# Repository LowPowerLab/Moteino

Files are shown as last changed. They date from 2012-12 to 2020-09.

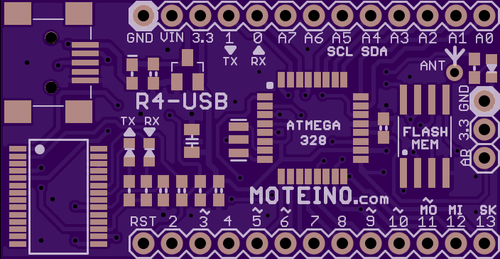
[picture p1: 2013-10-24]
R4USB/Rendering_top.png

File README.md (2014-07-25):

Moteino
=======

Moteino Eagle project and library.
Moteino is now shipping with DualOptiboot: https://github.com/LowPowerLab/DualOptiboot
DualOptiboot allows for wireless programming using an external FLASH chip soldered to Moteino on the provided footprint.

#License
CC-BY-SA 4.0
https://creativecommons.org/licenses/by-sa/4.0/
You are free to share and adapt. But you need to give attribution and use the same license to redistribute.

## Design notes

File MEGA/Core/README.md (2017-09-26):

# Moteino/MoteinoMEGA Arduino core files for Atmega328P/ATmega1284P based Moteinos

# * ~~~ Obsolete ~~~ *
See new instructions to get Moteino Core in the [Moteino guide](https://lowpowerlab.com/guide/moteino/programming-libraries/).

## What is it?
Everything you need to run a ATmega1284P based Moteino MEGA from the Arduino IDE.
Added regular Moteino variant based on the prolific ATmega328p.

## Status
* This Arduino core contains the ATmega1284P MoteinoMEGA variant and the ATmega328p Moteino variant (added Nov 2014) along with the DualOptiboot bootloaders.
* The platform now includes Dualoptiboot for ATmega1284P and ATmega328p which support [wireless programming](https://lowpowerlab.com/guide/moteino/wireless-programming/) (C) by Felix Rusu of LowPowerLab.com
* Last updated: Aug 24, 2016.

## License
This program is free software; you can redistribute it and/or modify it under the terms of the GNU General Public License as published by the Free Software Foundation; either version 3 of the License, or (at your option) any later version. This program is distributed in the hope that it will be useful, but WITHOUT ANY WARRANTY; without even the implied warranty of MERCHANTABILITY or FITNESS FOR A PARTICULAR PURPOSE. See the GNU General Public License for more details. View full license text at: http://www.gnu.org/licenses/gpl-3.0.txt

##Install Update
* This guide and package is only relevant for manual installs on IDE 1.6+ or the older 1.0.6.
* Arduino IDE 1.6.4+ has a board manager that makes it really easy to add the board definitions, instead of using these ZIP files. For installing via BoardManager in IDE 1.6.4+, see [this guide](https://lowpowerlab.com/moteino/#programming).

## Installation
0. Ensure you are running Arduino 1.6.0 or greater (this was tested on Arduino 1.6.9). For Arduino 1.0.6 use the Moteino_1.0.6.zip instead, read below.
1. Download the root of this repository [from here](https://github.com/LowPowerLab/Moteino) (find the "Clone or Download" button), then extract the Moteino core [ZIP File](https://github.com/LowPowerLab/Moteino/blob/master/MEGA/Core/Moteino.zip) from that. If you run the 1.0.6 release get the Moteino_1.0.6.zip instead.
2. From the master ZIP archive of the whole repository, find the [corresponding Moteino.zip file](https://github.com/LowPowerLab/Moteino/blob/master/MEGA/Core/Moteino.zip)
3. Unzip the content of the Moteino.zip into a folder called 'hardware' located in your sketches directory, e.g. /Users/felix/Arduino/hardware/Moteino. Some users report that they can only make this work by copying it directly in the hardware folder under their Arduino installation folder.
4. Restart the IDE
5. Select Tools > Board > Moteino or MoteinoMEGA
6. To burn the bootloader, follow the Arduino [Bootloader](http://arduino.cc/en/Hacking/Bootloader) instructions.

## Requirements
* Tested on stable Arduino 1.6.9
* According to maniacbug the bootloader cannot be burned using [USBtinyISP](http://www.ladyada.net/make/usbtinyisp/). That programmer cannot flash to chips with >64k flash size. I recommend using a true AVR programmer like the AVR ISP MKii.

## MISC - See also
ManiacBug's older [mighty-1284p arduino core](http://maniacbug.wordpress.com/2011/11/27/arduino-on-atmega1284p-4/) and 
Leonardo Milliani's [mods to mighty-1284p](http://www.leonardomiliani.com/2014/core-per-atmega644p1284p-aggiornato-per-lide-1-5-6-r2/).

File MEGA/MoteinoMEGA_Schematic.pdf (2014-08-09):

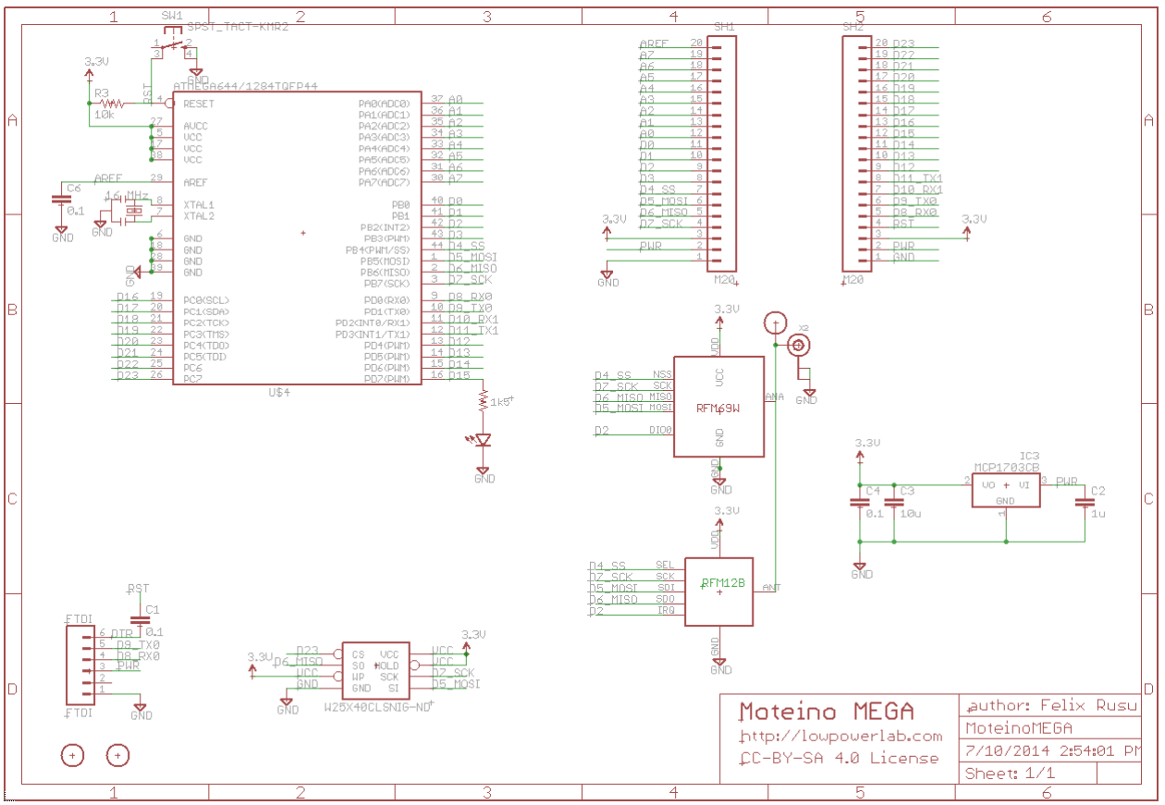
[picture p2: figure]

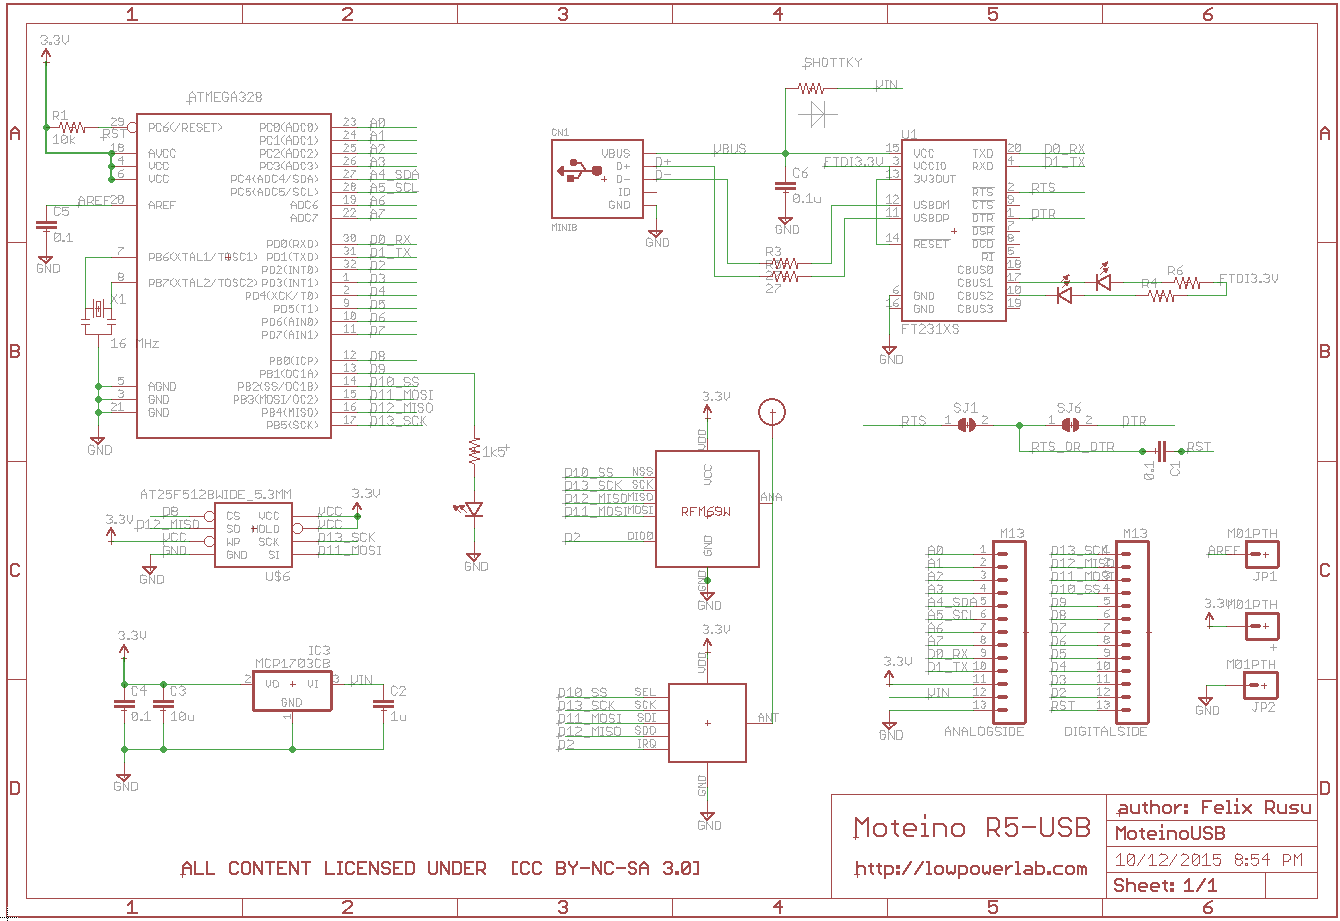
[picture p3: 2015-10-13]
R5USB/MoteinoR5USB_Schematic.png

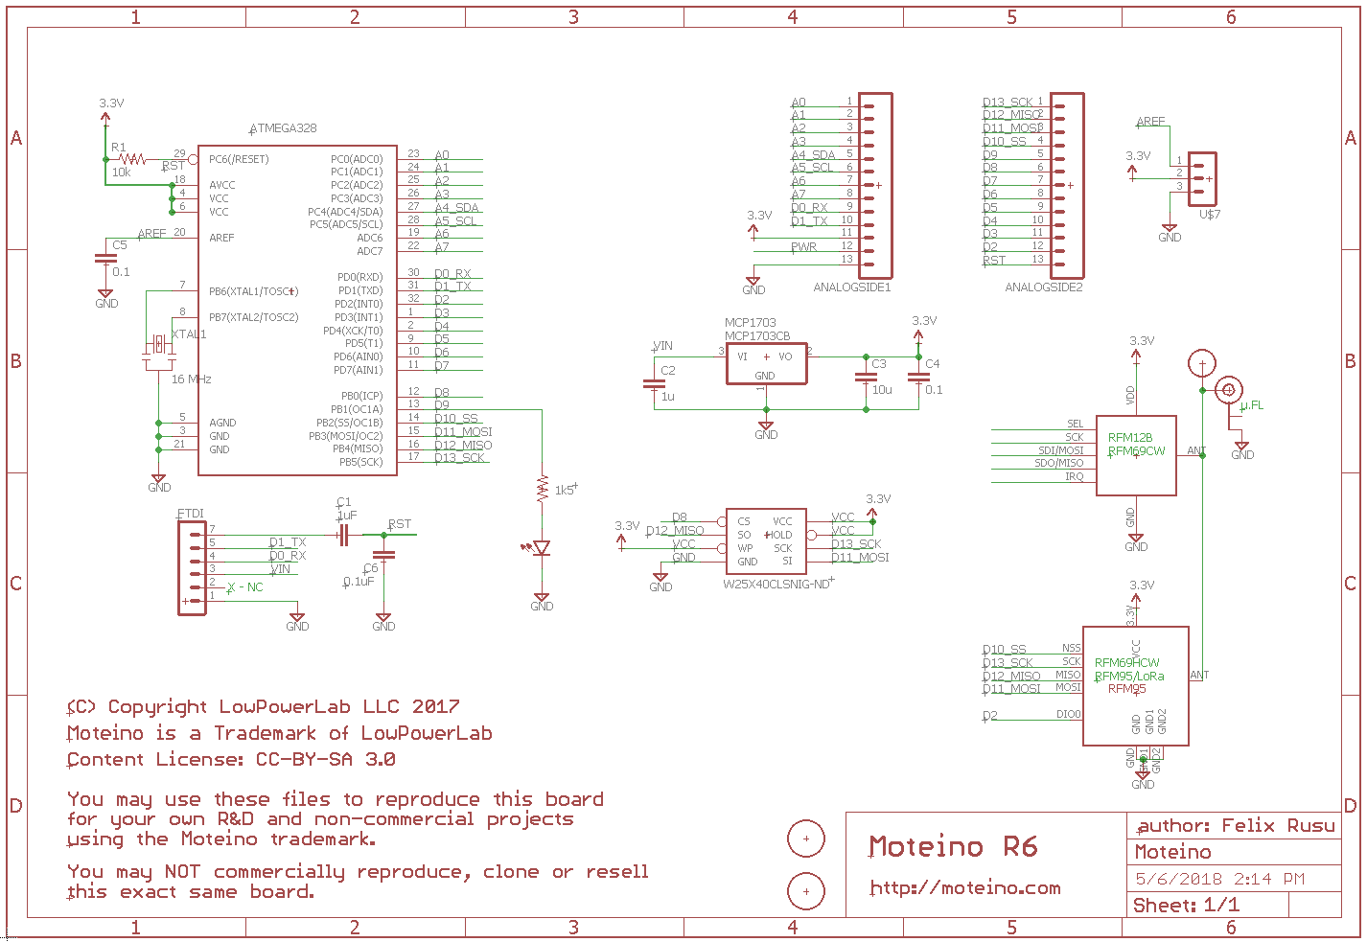
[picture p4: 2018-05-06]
R6/MoteinoR6_Schematic.png

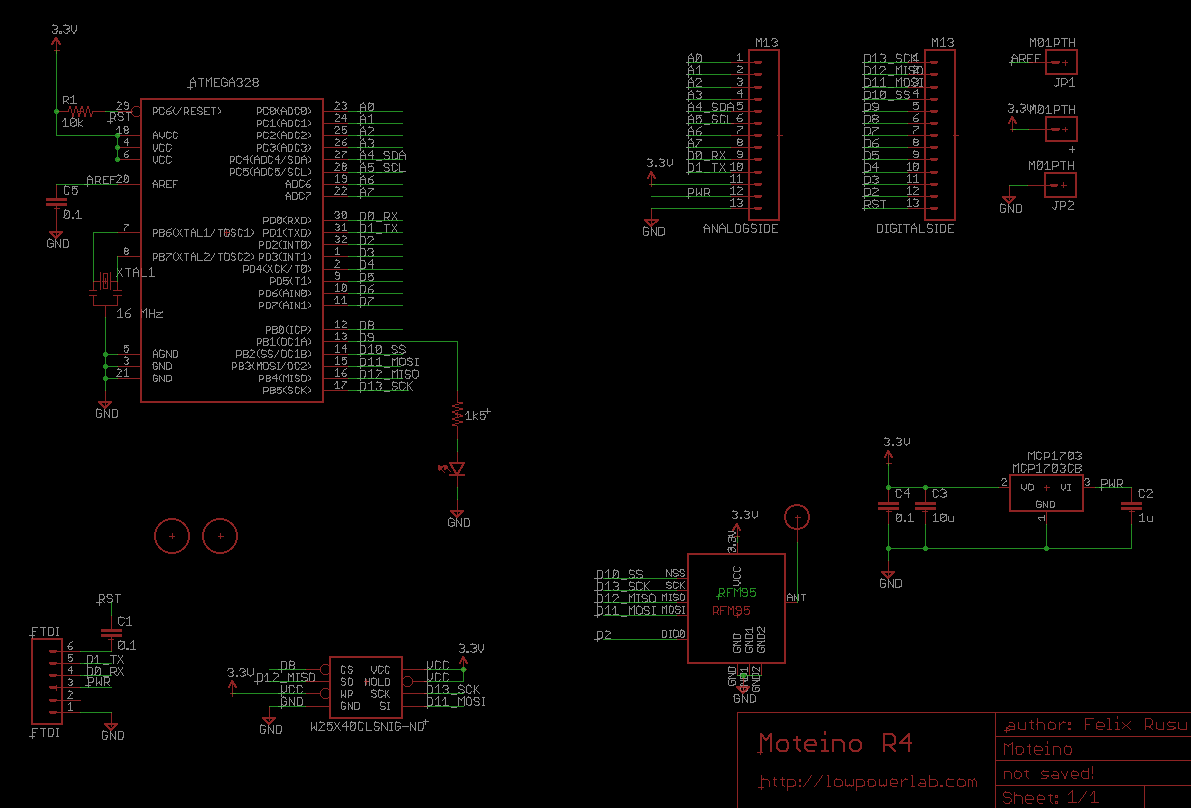
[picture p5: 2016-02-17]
R4/MoteinoR4LR_Schematic.png

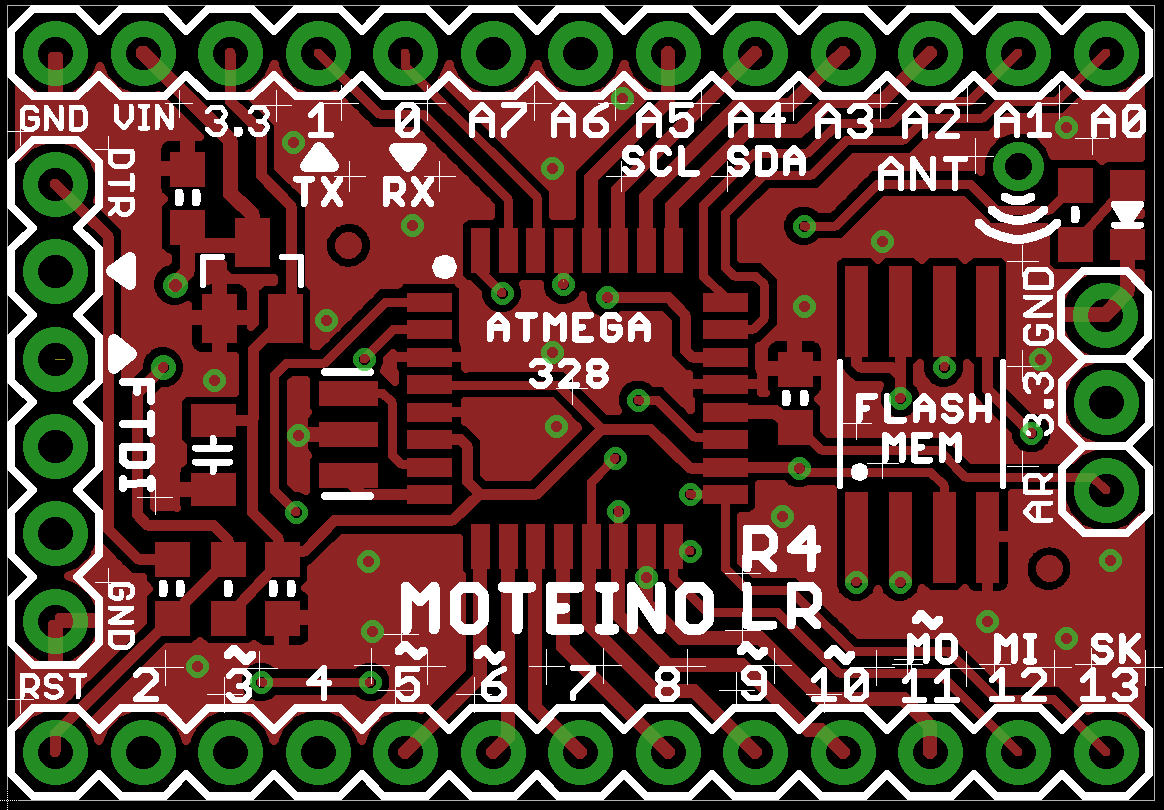
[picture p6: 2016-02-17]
R4/MoteinoR4LR_BRD_TOP.png

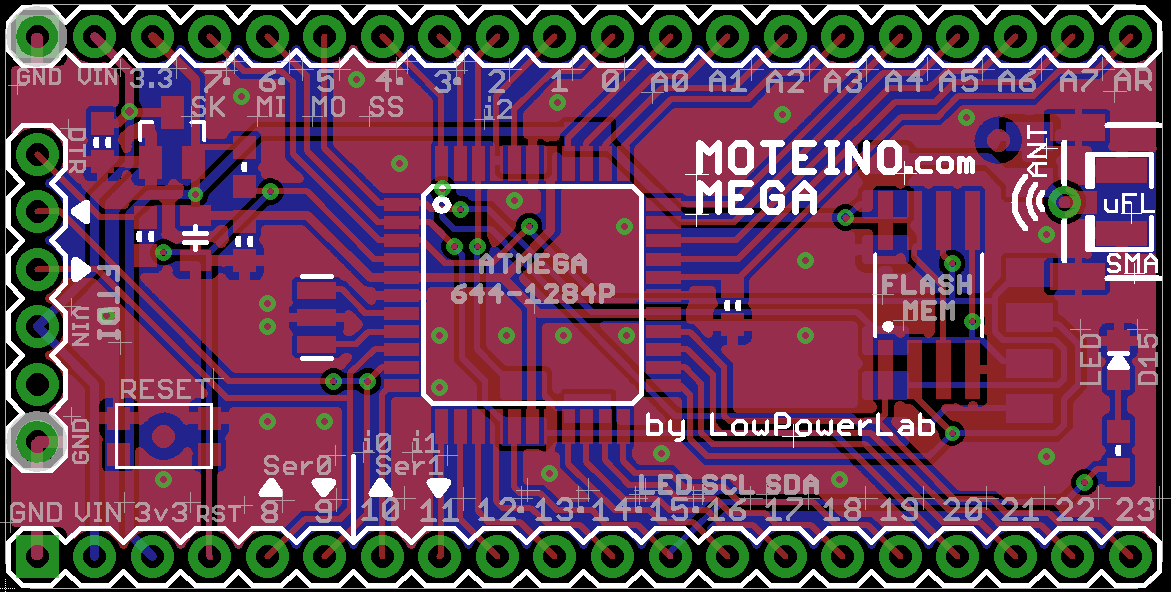
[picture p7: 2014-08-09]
MEGA/MoteinoMEGA_Board.png

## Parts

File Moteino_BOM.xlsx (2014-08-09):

 | QTY
MOTEINO
ATMega328P-AU TQFP32 | 1 | http://www.digikey.com/product-detail/en/ATMEGA328P-AU/ATMEGA328P-AU-ND/1832260
ATMega1284P-AU TQFP44 | 1 | http://www.digikey.com/product-detail/en/ATMEGA1284P-AU/ATMEGA1284P-AU-ND/1914519
Ceramic Res SMD 16Mhz | 1 | http://www.digikey.com/product-detail/en/CSTCE16M0V53-R0/490-1198-1-ND/584635
cap 0.1uf 0603 | 4 | http://www.digikey.com/product-detail/en/CC0603KRX7R7BB104/311-1088-1-ND/302998?cur=USD
cap 10uF | 1 | http://www.digikey.com/product-detail/en/CC0805ZKY5V6BB106/311-1355-1-ND/2103139
res 10k 0603 | 1 | http://www.digikey.com/product-detail/en/RC0603JR-0710KL/311-10KGRCT-ND/729647?cur=USD
MCP1703 3v3 (up to 16V in) | 1 | http://www.digikey.com/product-detail/en/MCP1703T-3302E%2FCB/MCP1703T-3302E%2FCBCT-ND/1776945
RFM12B | 1 | www.lowpowerlab.com/shop
RFM69 |  | www.lowpowerlab.com/shop
LED yellow - 0603 | 1 | http://www.digikey.com/product-detail/en/LY%20L29K-H1K2-26-Z/475-1196-1-ND/810357
res 1.5k 0603 (for LED) | 1 | http://www.digikey.com/scripts/DKSearch/dksus.dll?Detail&itemSeq=123239606&uq=634903057332793783
male headers | ? | http://www.digikey.com/product-detail/en/PRPC040SAAN-RC/S1011EC-40-ND/2775214
female headers | ? | http://www.digikey.com/product-detail/en/NPPN401BFCN-RC/S5751-40-ND/804821
PCB | 1 | Your favorite PCB fab
WIRE for antenna | 1 | 433Mhz:164.7mm, 868Mhz:82.2mm, 915Mhz:77.9mm (from here: http://blog.strobotics.com.au/2008/06/17/rfm12-tutorial-part2/)
You can use 1uF instead of 0.1uF
cap 1uf 0603 |  | http://www.digikey.com/product-detail/en/C1608Y5V1A105Z/445-1328-1-ND/567635

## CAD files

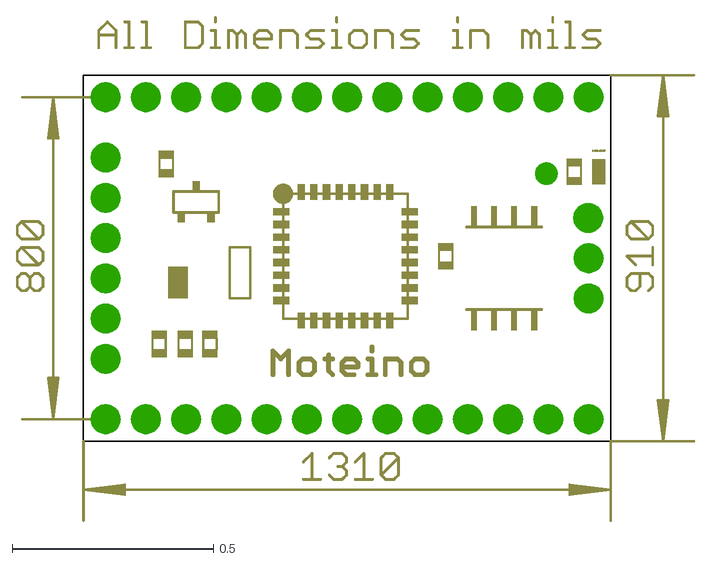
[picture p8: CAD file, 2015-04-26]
DXF/Moteino.dxf
1.69 x 1.26

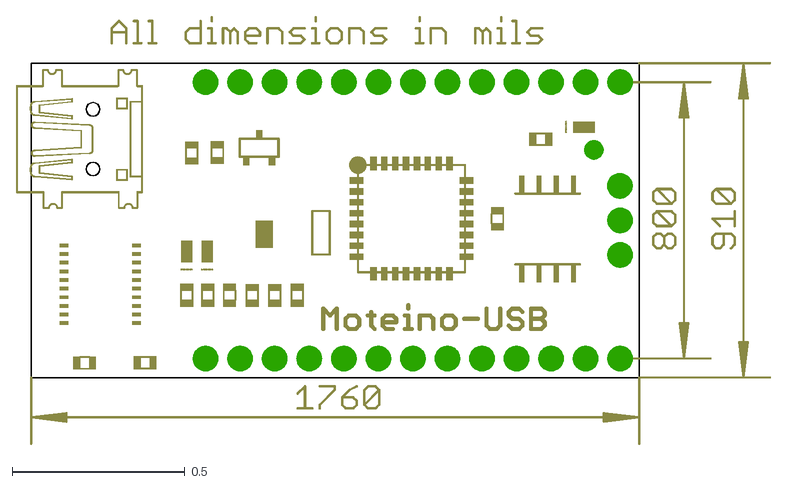
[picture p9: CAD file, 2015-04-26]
R5USB/MoteinoR5USB_dimension.dxf
2.18 x 1.24

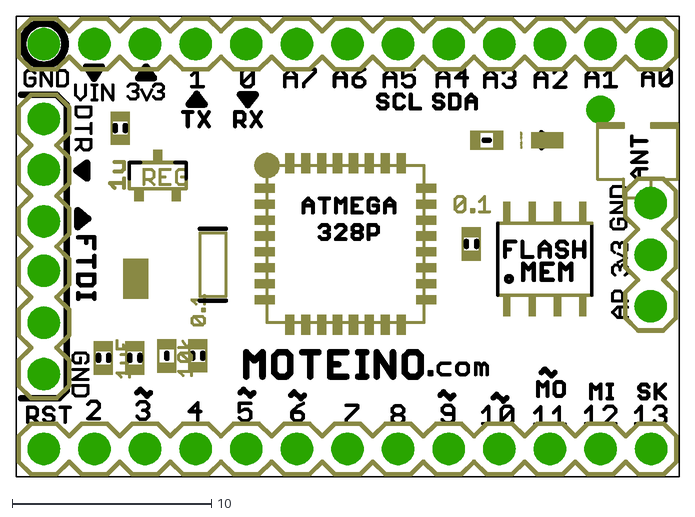
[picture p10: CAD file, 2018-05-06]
R6/Moteino.dxf
33.3 x 23.1

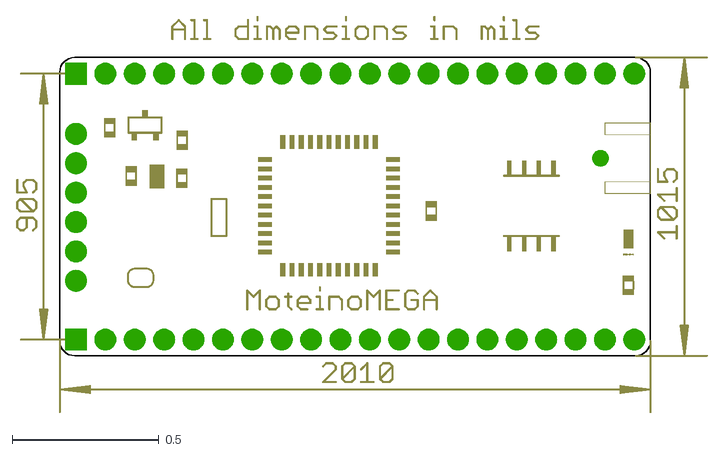
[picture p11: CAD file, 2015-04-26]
DXF/MoteinoMEGA.dxf
2.35 x 1.35

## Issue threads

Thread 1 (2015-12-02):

JSON-based package for Arduino 1.6.5+ Boards Manager?

rei-vilo, 2015-12-02:
Hi!

Do you plan to bundle the Motion files in a JSON-based package for Arduino 1.6.5+ Boards Manager?

Thank you,

whmountains, 2017-10-23:
Apparently the answer is yes.  The boards manager URL is: https://lowpowerlab.github.io/MoteinoCore/package_LowPowerLab_index.json

Closed 2017-10-23.

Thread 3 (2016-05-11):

Moteino_BOM error in URL

davegravy, 2016-05-11:
Line 13 in the BOM excel file "res 1.5k 0603 (for LED)" has a bad URL.

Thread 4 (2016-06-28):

Capacitor Replacement 0.1uF to 1uF

MiaranaDIY, 2016-06-28:
Hi Felix,

Thanks for the great work, but i need some help troubleshooting my home made moteino.
The board can not be programmed using Arduino IDE (error: not in sync and programmer is not responding). I'm building Moteino R4 (non usb), the PCB it self is from OSHPark, and using the same type usb FTDI programmer like yours.

One thing that i want to make sure, i read in the bill of material moteino board eagle file, that capacitor 0.1uF can be replaced using 1uF instead, is that true?

i worried, that is the cause, because i'm using 1uF instead of 0.1uF. Please give me some suggestion about the capacitor.

And the Arduino IDE i'm using version 1.6.9 with Moteino in board manager, but still not sure for the programmer mode that i should use, USBAsp or AVRISP mkII or other.

Any help will save my life

whmountains, 2017-10-23:
Hey @MiaranaDIY, fellow Moteino user here.  I'm sorry it's not working for you.

I suggest you ask for help in the LowPowerLab forums.  A lot of Moteino users hang out over there and I expect someone would have a suggestion.

As far as the capacitor values, I wouldn't recommend substituting capacitor values like that.  It's usually fine stabilizing the power rail and that sort of thing, but other circuits like the reset connection on the FTDI connector are more sensitive.

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

Replacing C1 with a capacitor that's 10x bigger is very likely to cause problems resetting the Atmega328P.  If you're impatient and don't want to wait for the right size capacitor to arrive, try triggering the reset manually by touching pin 6 of the FTDI to ground.

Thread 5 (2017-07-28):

R6 eagle files?

fatmcgav, 2017-07-28:
Hi @LowPowerLab

Firstly, thank-you for all your hard work on Moteino.

Are you intending to publish the R6 eagle files?

Cheers

LowPowerLab, 2017-07-28:
Not sure at this point. The R5 is almost identical. See forum for schematic.
Not an issue so closing this, please ask similar questions in the forum, thanks.

fatmcgav, 2017-07-28:
No worries, cheers for quick response.

Closed 2017-07-28.

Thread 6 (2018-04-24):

missing component in Moteuino Mega BOM file

designDemon, 2018-04-24:
Hey
It seems like the exact part no. and link for the reset switch is
missing in the BOM file. Could you please share the exact
component details here.

Thanks

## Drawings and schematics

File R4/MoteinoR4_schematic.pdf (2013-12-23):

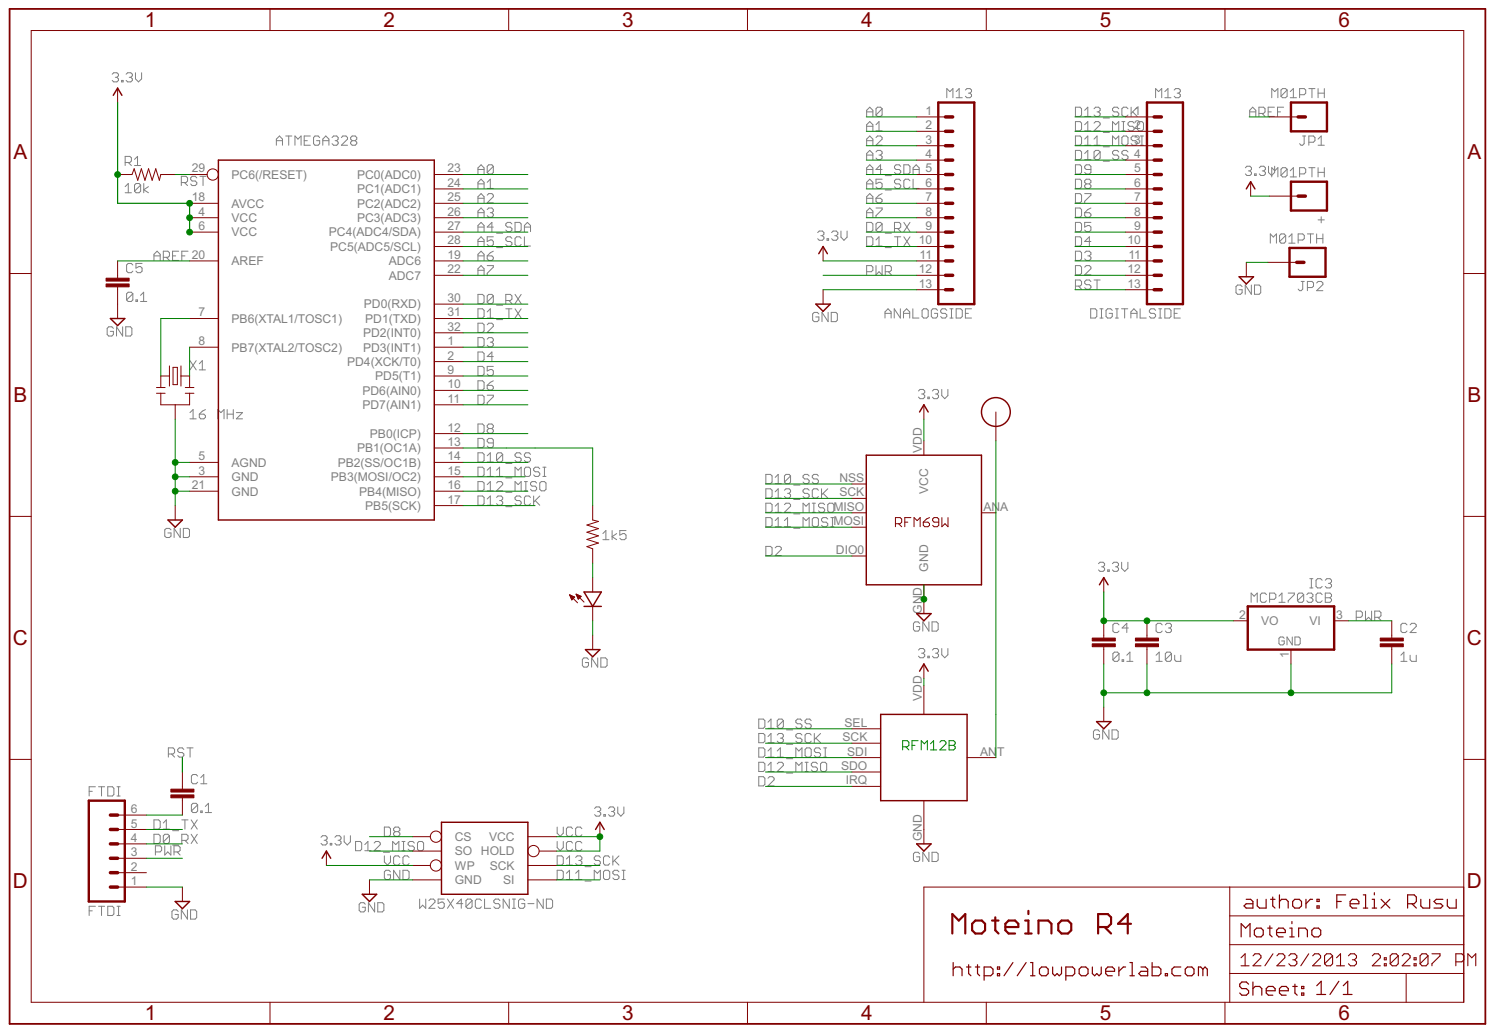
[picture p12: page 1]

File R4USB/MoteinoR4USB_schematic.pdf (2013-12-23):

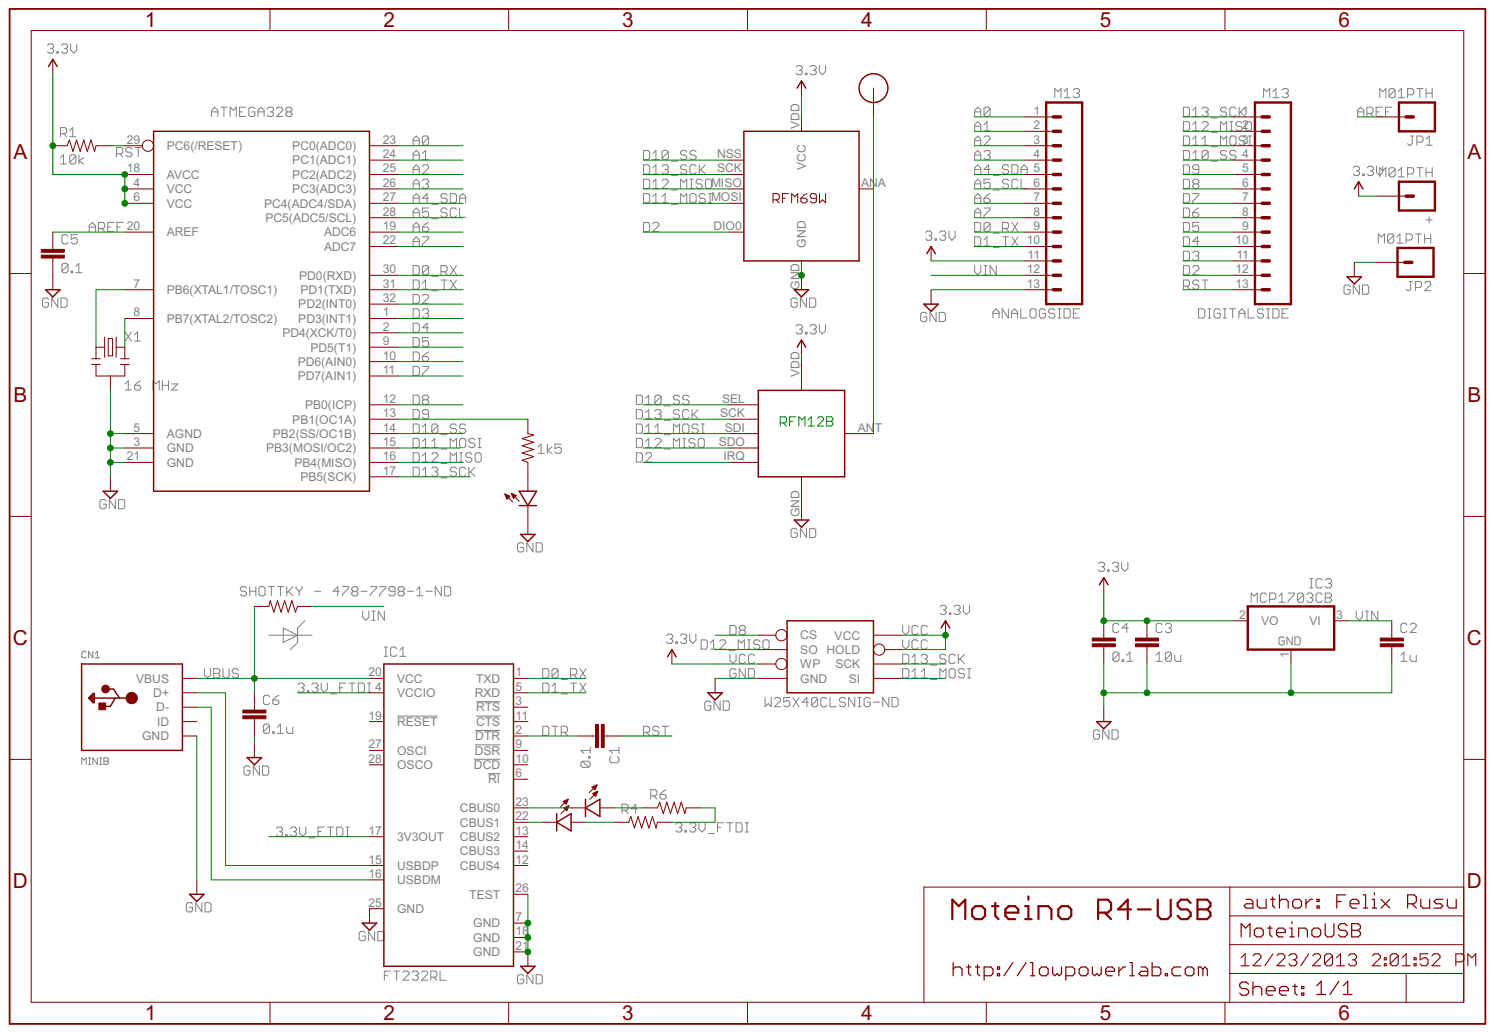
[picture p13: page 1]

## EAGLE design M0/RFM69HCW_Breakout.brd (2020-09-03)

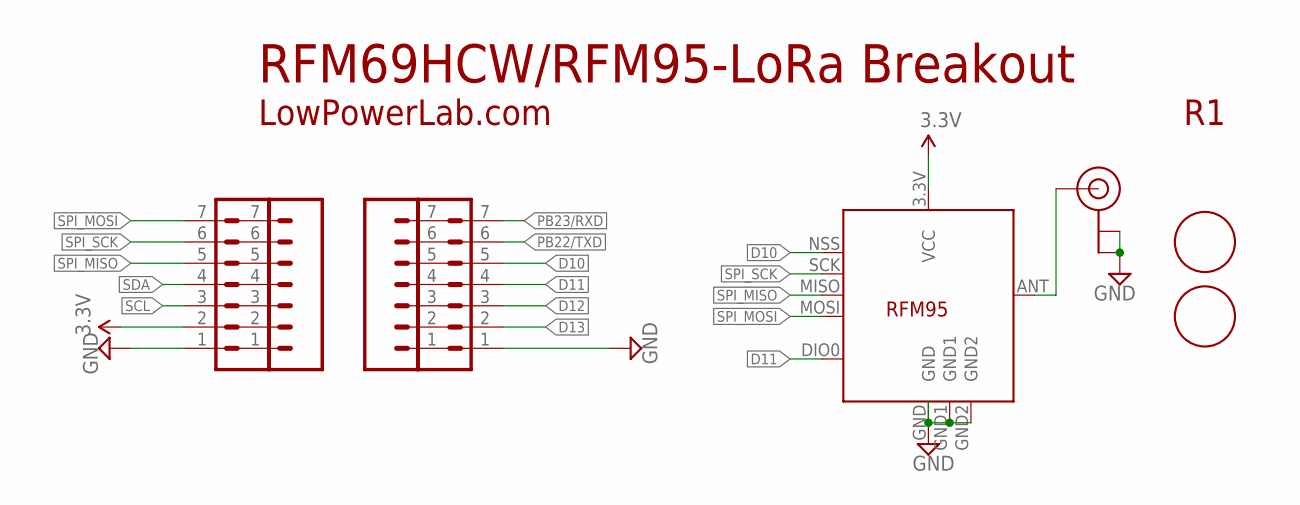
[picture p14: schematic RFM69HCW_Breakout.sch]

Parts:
FIDUCIAL_UPPERLEFT: FIDUCIAL1.5MM; FIDUCIAL_1.5MM
U$4, U$10: HDR_7PINNS_THINRINGS; 1X07_NS_THINRINGS
U$9: FIDUCIAL1.5MM; FIDUCIAL_1.5MM
U$16: RFM95COMPACT; RFM95
U$17, U$18: HDR_7PINHH; 1X07_NS_THINRINGS_HH
X2: U.FLW; U.FL_WIDER

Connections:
3.3V: U$16.3.3V (VCC), U$18.2
ANT: U$16.ANT, X2.SIGNAL
D10: U$16.NSS (SEL), U$17.5
D11: U$16.DIO0, U$17.4
D12: U$17.3
D13: U$17.2
GND: U$16.GND, U$16.GND1, U$16.GND2, U$17.1, U$18.1, X2.GND1 (GND), X2.GND2 (GND)
PB22/TXD: U$17.6
PB23/RXD: U$17.7
SCL: U$18.3
SDA: U$18.4
SPI_MISO: U$16.MISO, U$18.5
SPI_MOSI: U$16.MOSI, U$18.7
SPI_SCK: U$16.SCK, U$18.6

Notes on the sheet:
LowPowerLab.com
RFM69HCW/RFM95-LoRa Breakout

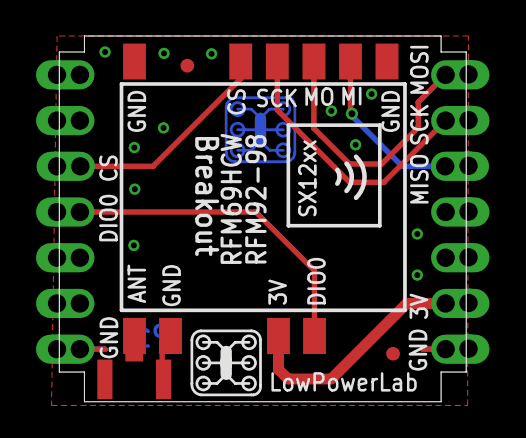
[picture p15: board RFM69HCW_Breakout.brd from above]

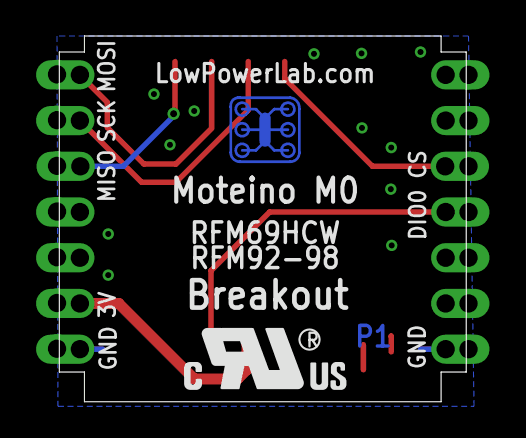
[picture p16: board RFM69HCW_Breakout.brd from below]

Board: 2 copper layers, 22.6 x 20.3 mm, 12 parts (4 on the bottom side), 8 nets.

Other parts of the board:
U$1: LOGO_LOWPOWERLAB
U$2: LOGO_UL
U$3: LOGO_LOWPOWERLAB_COPPER
U$7: LOGO_LOWPOWERLAB_STOP

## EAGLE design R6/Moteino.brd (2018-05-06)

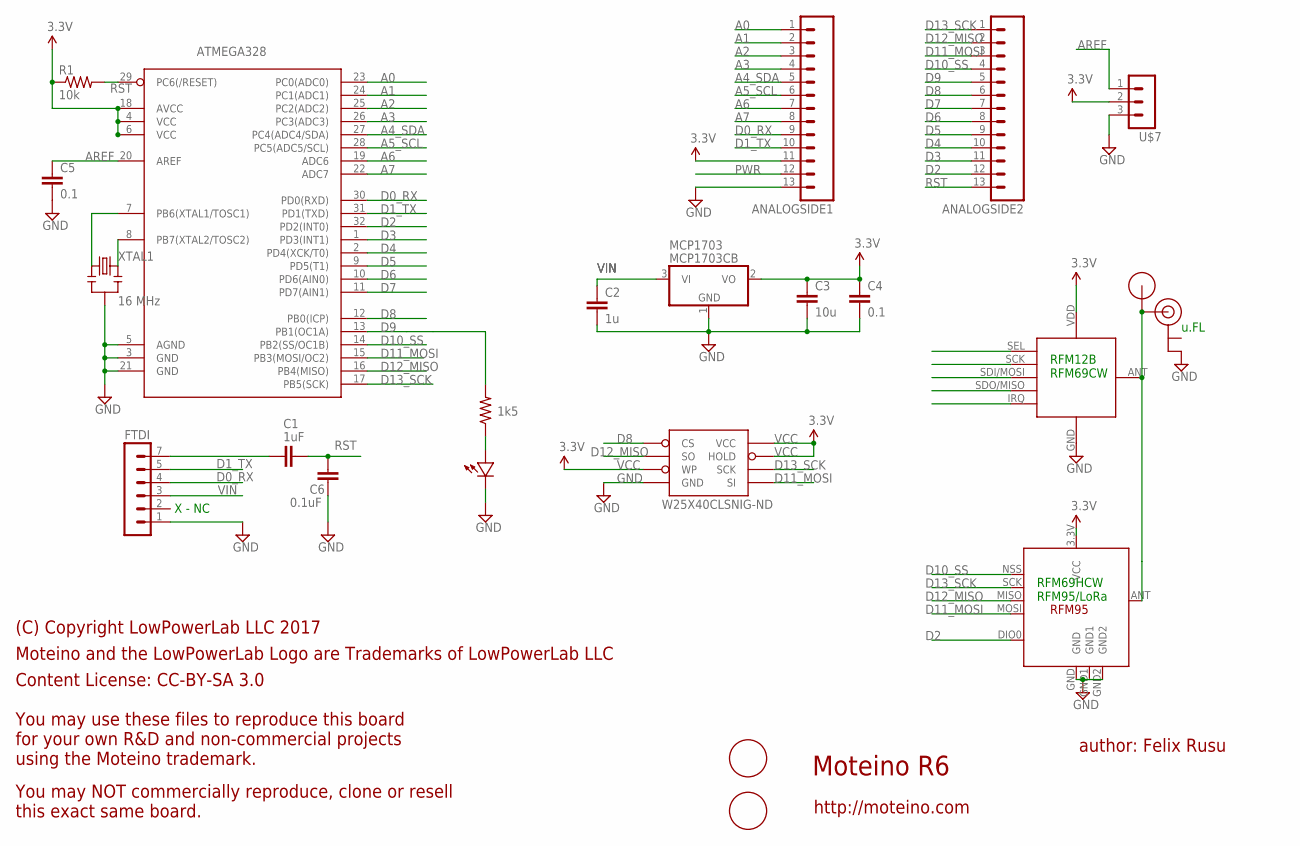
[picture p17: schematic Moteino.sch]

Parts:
ANALOGSIDE1, ANALOGSIDE2: HDR_13PINTHIN_RINGS; 1X13_THINRINGS
ATMEGA328: ATMega-328; TQFP32-08
C1: 1uF; 0603-CAP
C2: 1u; 0603-CAP
C3: 10u; 0805-CAP
C4, C5: 0.1; 0603-CAP
C6: 0.1uF; 0603-CAP
FTDI: HDR_6PINTHINRINGS; 1X06_NS_THINRINGS
LED: LED0603; 0603-LED
MCP1703: MCP1703CB; SOT23
R1: 10k; 0603-RES
R2: 1k5; 0603-RES
U$1: RFM12B_ANTENNA""; RFM12B-ANTENNA
U$2: RFM95LONGER; RFM95_LONGER
U$4: U.FL
U$5, U$6: FIDUCIAL1.5MM; FIDUCIAL_1.5MM
U$7: HDR_3PINTHINRINGS; 1X03_NS_THINRINGS
U$8: RFM12B_MINPADS; RFM12B-MINPADS
W25X40CLSNIG-ND: AT25F512BJEDEC_3.9MM; SO08
XTAL1: 16 MHz; RESONATOR-SMD

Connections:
A0: ANALOGSIDE1.1, ATMEGA328.23 (PC0(ADC0))
A1: ANALOGSIDE1.2, ATMEGA328.24 (PC1(ADC1))
A2: ANALOGSIDE1.3, ATMEGA328.25 (PC2(ADC2))
A3: ANALOGSIDE1.4, ATMEGA328.26 (PC3(ADC3))
A4_SDA: ANALOGSIDE1.5, ATMEGA328.27 (PC4(ADC4/SDA))
A5_SCL: ANALOGSIDE1.6, ATMEGA328.28 (PC5(ADC5/SCL))
A6: ANALOGSIDE1.7, ATMEGA328.19 (ADC6)
A7: ANALOGSIDE1.8, ATMEGA328.22 (ADC7)
AREF: ATMEGA328.20 (AREF), C5.1, U$7.1
D0_RX: ANALOGSIDE1.9, ATMEGA328.30 (PD0(RXD)), FTDI.4
D1_TX: ANALOGSIDE1.10, ATMEGA328.31 (PD1(TXD)), FTDI.5
D2: ANALOGSIDE2.12, ATMEGA328.32 (PD2(INT0)), U$2.DIO0, U$8.IRQ
D3: ANALOGSIDE2.11, ATMEGA328.1 (PD3(INT1))
D4: ANALOGSIDE2.10, ATMEGA328.2 (PD4(XCK/T0))
D5: ANALOGSIDE2.9, ATMEGA328.9 (PD5(T1))
D6: ANALOGSIDE2.8, ATMEGA328.10 (PD6(AIN0))
D7: ANALOGSIDE2.7, ATMEGA328.11 (PD7(AIN1))
D8: ANALOGSIDE2.6, ATMEGA328.12 (PB0(ICP)), W25X40CLSNIG-ND.1_CS (CS)
D9: ANALOGSIDE2.5, ATMEGA328.13 (PB1(OC1A)), R2.2
D10_SS: ANALOGSIDE2.4, ATMEGA328.14 (PB2(SS/OC1B)), U$2.NSS (SEL), U$8.SEL
D11_MOSI: ANALOGSIDE2.3, ATMEGA328.15 (PB3(MOSI/OC2)), U$2.MOSI, U$8.SDI/MOSI, W25X40CLSNIG-ND.5_SI (SI)
D12_MISO: ANALOGSIDE2.2, ATMEGA328.16 (PB4(MISO)), U$2.MISO, U$8.SDO/MISO, W25X40CLSNIG-ND.2_SO (SO)
D13_SCK: ANALOGSIDE2.1, ATMEGA328.17 (PB5(SCK)), U$2.SCK, U$8.SCK, W25X40CLSNIG-ND.6_SCK (SCK)
GND: ANALOGSIDE1.13, ATMEGA328.3 (GND), ATMEGA328.5 (AGND), ATMEGA328.21 (GND), C2.2, C3.2, C4.2, C5.2, C6.2, FTDI.1, LED.MINUS, MCP1703.1 (GND), U$2.GND, U$2.GND1, U$2.GND2, U$4.GND2 (GND), U$7.3, U$8.GND, W25X40CLSNIG-ND.4_GND (GND), XTAL1.2
unnamed: ATMEGA328.7 (PB6(XTAL1/TOSC1)), XTAL1.1
unnamed: LED.PLUS, R2.1
unnamed: U$1.P$1, U$2.ANT, U$4.SIGNAL, U$8.ANT
unnamed: C1.2, FTDI.7 (6)
unnamed: ATMEGA328.8 (PB7(XTAL2/TOSC2)), XTAL1.3
PWR: ANALOGSIDE1.12
RST: ANALOGSIDE2.13, ATMEGA328.29 (PC6(/RESET)), C1.1, C6.1, R1.2
VCC: ANALOGSIDE1.11, ATMEGA328.4 (VCC), ATMEGA328.6 (VCC), ATMEGA328.18 (AVCC), C3.1, C4.1, MCP1703.2 (VO), R1.1, U$2.3.3V (VCC), U$7.2, U$8.VDD, W25X40CLSNIG-ND.3_WP (WP), W25X40CLSNIG-ND.7_HOLD (HOLD), W25X40CLSNIG-ND.8_VCC (VCC)
VIN: C2.1, FTDI.3, MCP1703.3 (VI)

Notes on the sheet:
Moteino R6
author: Felix Rusu
http://moteino.com
RFM69HCW RFM95/LoRa
RFM12B RFM69CW
X - NC
u.FL
(C) Copyright LowPowerLab LLC 2017
Moteino and the LowPowerLab Logo are Trademarks of LowPowerLab LLC
Content License: CC-BY-SA 3.0
You may use these files to reproduce this board for your own R&D and non-commercial projects using the Moteino trademark.
You may NOT commercially reproduce, clone or resell this exact same board.

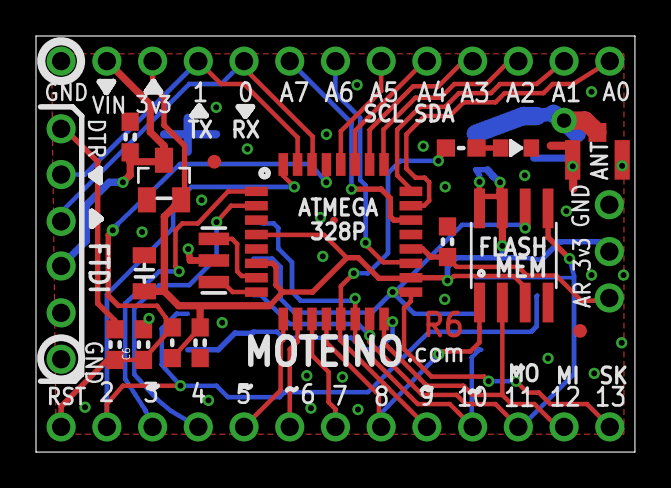
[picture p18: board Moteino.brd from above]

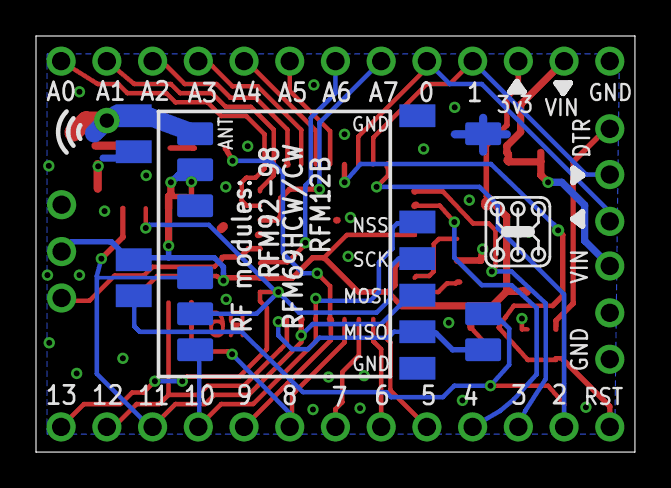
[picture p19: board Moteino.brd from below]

Board: 2 copper layers, 33.3 x 23.1 mm, 24 parts (3 on the bottom side), 32 nets.

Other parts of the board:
U$3: LOGO_LOWPOWERLAB

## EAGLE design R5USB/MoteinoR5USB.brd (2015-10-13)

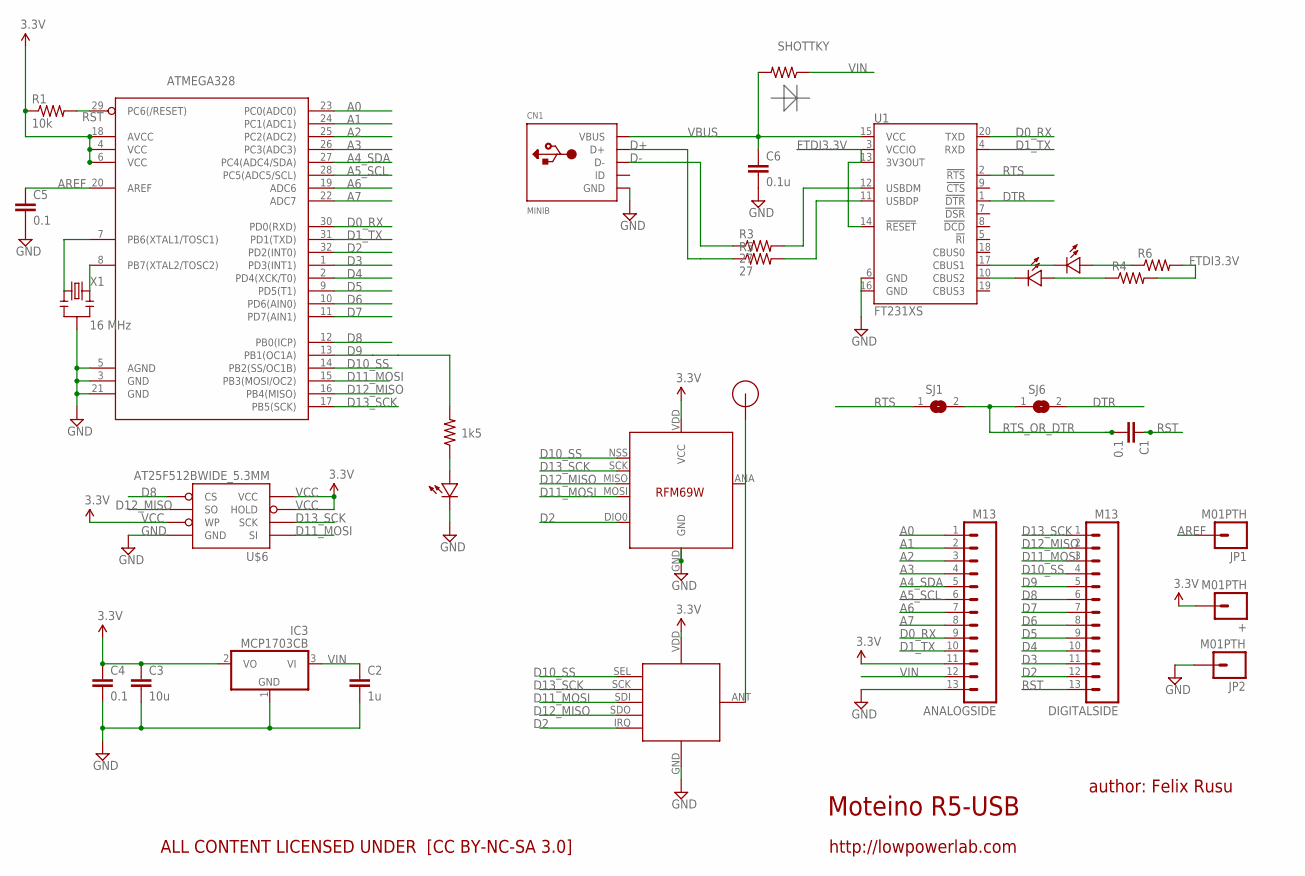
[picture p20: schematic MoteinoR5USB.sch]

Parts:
+: M01PTH; 1X01
ANALOGSIDE: M13; 1X13
ATMEGA328: ATMega-328; TQFP32-08
C1, C4, C5: 0.1; 0603-CAP
C2: 1u; 0603-CAP
C3: 10u; 0805-CAP
C6: 0.1u; 0603-CAP
CN1: MINIB; USB-MINIB
D: SHOTTKY; 0603-RES
DIGITALSIDE: M13; 1X13
IC3: MCP1703CB; SOT23
JP1, JP2: M01PTH; 1X01
R1: 10k; 0603-RES
R2: 1k5; 0603-RES
R3, R5: 27; 0603-RES
R4, R6: RESISTOR0603-RES; 0603-RES
RFM12B: RFM12B_MINPADS; RFM12B-MINPADS
SJ1, SJ6: JUMPER; SJW
U1: FT231XS; SSOP20_L
U$1: RFM12B_ANTENNA; RFM12B-ANTENNA
U$2, U$4, U$7: LED0603; 0603-LED
U$5: RFM69; RFM69W-MINPADS
U$6: AT25F512BWIDE_5.3MM; SO08WIDE
X1: 16 MHz; RESONATOR-SMD

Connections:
A0: ANALOGSIDE.1, ATMEGA328.23 (PC0(ADC0))
A1: ANALOGSIDE.2, ATMEGA328.24 (PC1(ADC1))
A2: ANALOGSIDE.3, ATMEGA328.25 (PC2(ADC2))
A3: ANALOGSIDE.4, ATMEGA328.26 (PC3(ADC3))
A4_SDA: ANALOGSIDE.5, ATMEGA328.27 (PC4(ADC4/SDA))
A5_SCL: ANALOGSIDE.6, ATMEGA328.28 (PC5(ADC5/SCL))
A6: ANALOGSIDE.7, ATMEGA328.19 (ADC6)
A7: ANALOGSIDE.8, ATMEGA328.22 (ADC7)
AREF: ATMEGA328.20 (AREF), C5.1, JP1.1
D0_RX: ANALOGSIDE.9, ATMEGA328.30 (PD0(RXD)), U1.20 (TXD)
D1_TX: ANALOGSIDE.10, ATMEGA328.31 (PD1(TXD)), U1.4 (RXD)
D2: ATMEGA328.32 (PD2(INT0)), DIGITALSIDE.12, RFM12B.IRQ, U$5.DIO0
D3: ATMEGA328.1 (PD3(INT1)), DIGITALSIDE.11
D4: ATMEGA328.2 (PD4(XCK/T0)), DIGITALSIDE.10
D5: ATMEGA328.9 (PD5(T1)), DIGITALSIDE.9
D6: ATMEGA328.10 (PD6(AIN0)), DIGITALSIDE.8
D7: ATMEGA328.11 (PD7(AIN1)), DIGITALSIDE.7
D8: ATMEGA328.12 (PB0(ICP)), DIGITALSIDE.6, U$6.1 (CS)
D9: ATMEGA328.13 (PB1(OC1A)), DIGITALSIDE.5, R2.2
D10_SS: ATMEGA328.14 (PB2(SS/OC1B)), DIGITALSIDE.4, RFM12B.SEL, U$5.NSS (SEL)
D11_MOSI: ATMEGA328.15 (PB3(MOSI/OC2)), DIGITALSIDE.3, RFM12B.SDI (SDI/MOSI), U$5.MOSI, U$6.5 (SI)
D12_MISO: ATMEGA328.16 (PB4(MISO)), DIGITALSIDE.2, RFM12B.SDO (SDO/MISO), U$5.MISO, U$6.2 (SO)
D13_SCK: ATMEGA328.17 (PB5(SCK)), DIGITALSIDE.1, RFM12B.SCK, U$5.SCK, U$6.6 (SCK)
D+: CN1.D+, R5.1
D-: CN1.D-, R3.1
DTR: SJ6.2, U1.1 (!DTR)
FTDI3.3V: R4.2, R6.2, U1.3 (VCCIO), U1.13 (3V3OUT), U1.14 (!RESET)
GND: ANALOGSIDE.13, ATMEGA328.3 (GND), ATMEGA328.5 (AGND), ATMEGA328.21 (GND), C2.2, C3.2, C4.2, C5.2, C6.2, CN1.GND, IC3.1 (GND), JP2.1, RFM12B.GND, U1.6 (GND), U1.16 (GND), U$2.MINUS, U$5.GND, U$6.4 (GND), X1.2
unnamed: ATMEGA328.7 (PB6(XTAL1/TOSC1)), X1.1
unnamed: R2.1, U$2.PLUS
unnamed: RFM12B.ANT, U$1.P$1, U$5.ANA (ANT)
unnamed: R3.2, U1.12 (USBDM)
unnamed: R5.2, U1.11 (USBDP)
unnamed: U1.17 (CBUS1), U$4.MINUS
unnamed: U1.10 (CBUS2), U$7.MINUS
unnamed: R4.1, U$7.PLUS
unnamed: R6.1, U$4.PLUS
unnamed: ATMEGA328.8 (PB7(XTAL2/TOSC2)), X1.3
RST: ATMEGA328.29 (PC6(/RESET)), C1.1, DIGITALSIDE.13, R1.2
RTS: SJ1.1, U1.2 (!RTS)
RTS_OR_DTR: C1.2, SJ1.2, SJ6.1
VBUS: C6.1, CN1.VBUS, D.2, U1.15 (VCC)
VCC: +.1, ANALOGSIDE.11, ATMEGA328.4 (VCC), ATMEGA328.6 (VCC), ATMEGA328.18 (AVCC), C3.1, C4.1, IC3.2 (VO), R1.1, RFM12B.VDD, U$5.VDD (VCC), U$6.3 (WP), U$6.7 (HOLD), U$6.8 (VCC)
VIN: ANALOGSIDE.12, C2.1, D.1, IC3.3 (VI)

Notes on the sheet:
Moteino R5-USB
author: Felix Rusu
http://lowpowerlab.com
ALL CONTENT LICENSED UNDER [CC BY-NC-SA 3.0]

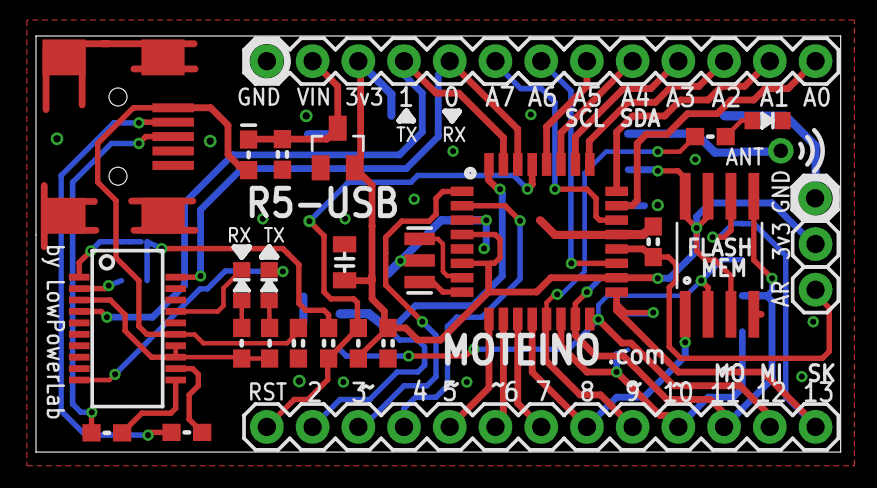
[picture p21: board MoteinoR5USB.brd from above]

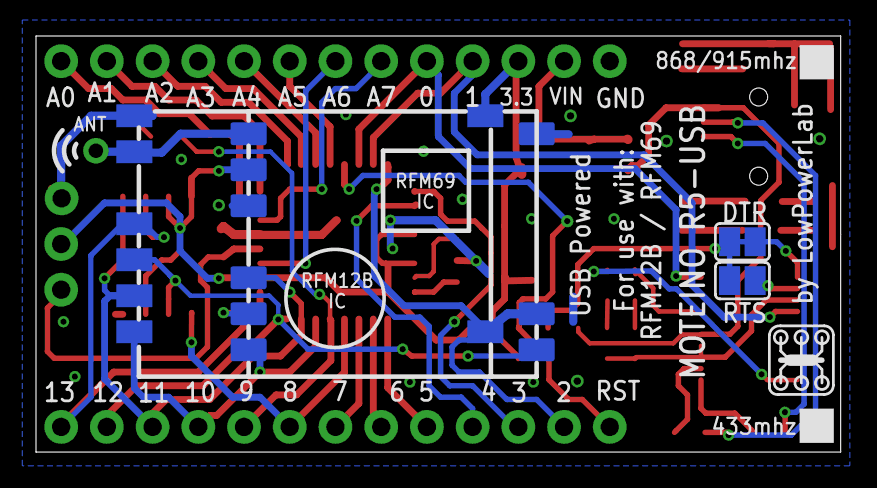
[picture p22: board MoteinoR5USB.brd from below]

Board: 2 copper layers, 44.7 x 23.1 mm, 33 parts (5 on the bottom side), 44 nets.

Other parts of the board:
U$3: LOGO_LOWPOWERLAB

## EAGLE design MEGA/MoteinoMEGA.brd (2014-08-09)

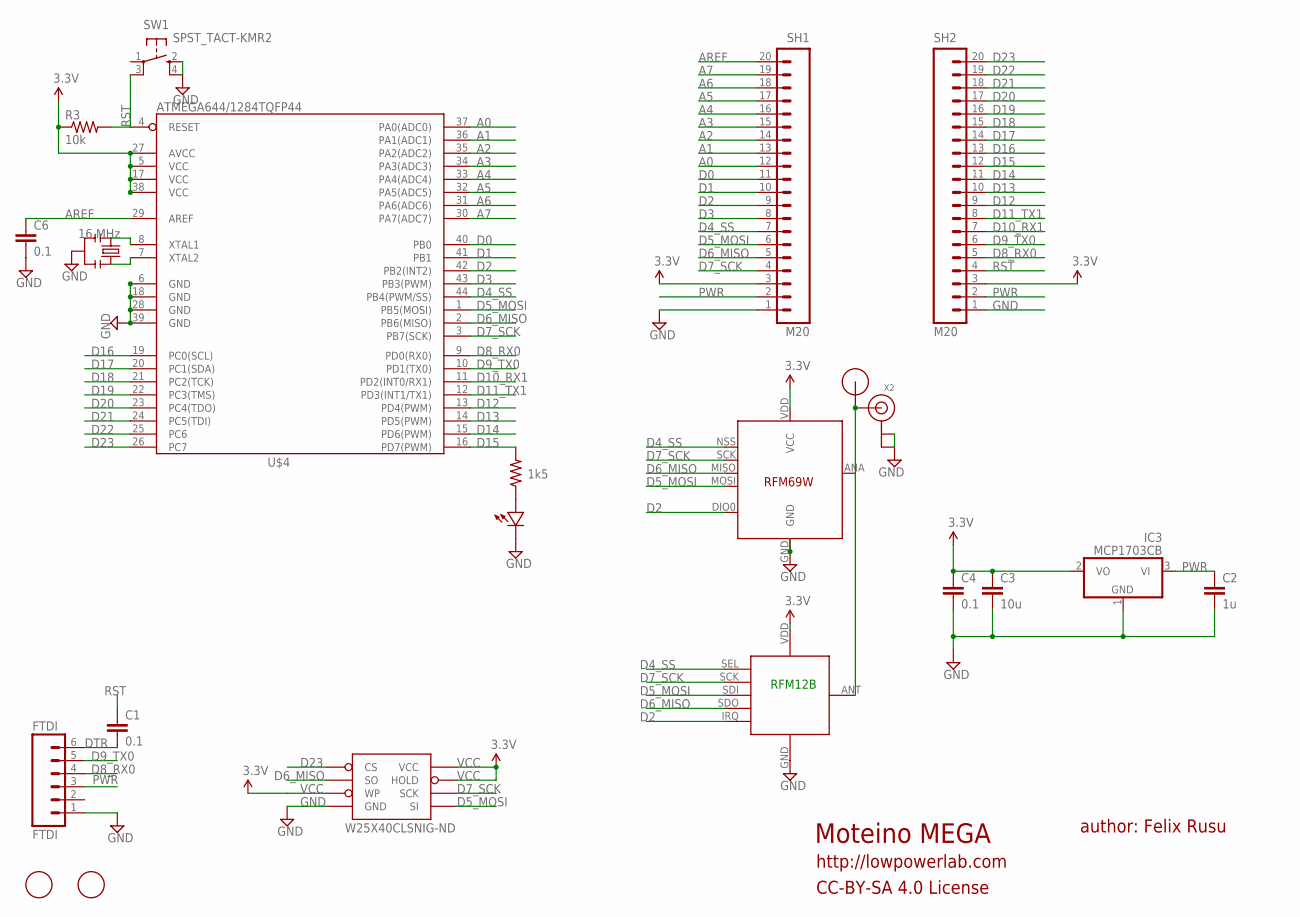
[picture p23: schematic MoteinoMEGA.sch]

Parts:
C1, C4, C6: 0.1; 0603-CAP
C2: 1u; 0603-CAP
C3: 10u; 0805-CAP
FTDI: FTDI; 1X06
IC3: MCP1703CB; SOT23
R2: 1k5; 0603-RES
R3: 10k; 0603-RES
RFM12B: RFM12B_MINPADS; RFM12B-MINPADS
SH1, SH2: M20; 1X20
SW1: SPST_TACT-KMR2; KMR2
U$1: RFM12B_ANTENNA; RFM12B-ANTENNA
U$2, U$7: FIDUCIAL; FIDUCIAL_1MM
U$4: ATMEGA644/1284TQFP44; TQFP44
U$5: RFM69; RFM69W-MINPADS
U$6: LED0603; 0603-LED
W25X40CLSNIG-ND: AT25F512BWIDE_5.3MM; SO08WIDE
X1: 16 MHz; RESONATOR-SMD
X2: ANTENNA_U.FL; U.FL

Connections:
A0: SH1.12, U$4.37 (PA0(ADC0))
A1: SH1.13, U$4.36 (PA1(ADC1))
A2: SH1.14, U$4.35 (PA2(ADC2))
A3: SH1.15, U$4.34 (PA3(ADC3))
A4: SH1.16, U$4.33 (PA4(ADC4))
A5: SH1.17, U$4.32 (PA5(ADC5))
A6: SH1.18, U$4.31 (PA6(ADC6))
A7: SH1.19, U$4.30 (PA7(ADC7))
AREF: C6.1, SH1.20, U$4.29 (AREF)
D0: SH1.11, U$4.40 (PB0)
D1: SH1.10, U$4.41 (PB1)
D2: RFM12B.IRQ, SH1.9, U$4.42 (PB2(INT2)), U$5.DIO0
D3: SH1.8, U$4.43 (PB3(PWM))
D4_SS: RFM12B.SEL, SH1.7, U$4.44 (PB4(PWM/SS)), U$5.NSS (SEL)
D5_MOSI: RFM12B.SDI (SDI/MOSI), SH1.6, U$4.1 (PB5(MOSI)), U$5.MOSI, W25X40CLSNIG-ND.5 (SI)
D6_MISO: RFM12B.SDO (SDO/MISO), SH1.5, U$4.2 (PB6(MISO)), U$5.MISO, W25X40CLSNIG-ND.2 (SO)
D7_SCK: RFM12B.SCK, SH1.4, U$4.3 (PB7(SCK)), U$5.SCK, W25X40CLSNIG-ND.6 (SCK)
D8_RX0: FTDI.4, SH2.5, U$4.9 (PD0(RX0))
D9_TX0: FTDI.5, SH2.6, U$4.10 (PD1(TX0))
D10_RX1: SH2.7, U$4.11 (PD2(INT0/RX1))
D11_TX1: SH2.8, U$4.12 (PD3(INT1/TX1))
D12: SH2.9, U$4.13 (PD4(PWM))
D13: SH2.10, U$4.14 (PD5(PWM))
D14: SH2.11, U$4.15 (PD6(PWM))
D15: R2.2, SH2.12, U$4.16 (PD7(PWM))
D16: SH2.13, U$4.19 (PC0(SCL))
D17: SH2.14, U$4.20 (PC1(SDA))
D18: SH2.15, U$4.21 (PC2(TCK))
D19: SH2.16, U$4.22 (PC3(TMS))
D20: SH2.17, U$4.23 (PC4(TDO))
D21: SH2.18, U$4.24 (PC5(TDI))
D22: SH2.19, U$4.25 (PC6)
D23: SH2.20, U$4.26 (PC7), W25X40CLSNIG-ND.1 (CS)
DTR: C1.2, FTDI.6
GND: C2.2, C3.2, C4.2, C6.2, FTDI.1, IC3.1 (GND), RFM12B.GND, SH1.1, SH2.1, SW1.2 (S), SW1.4 (S1), U$4.6 (GND), U$4.18 (GND), U$4.28 (GND), U$4.39 (GND), U$5.GND, U$6.MINUS, W25X40CLSNIG-ND.4 (GND), X1.2, X2.1 (GND), X2.2 (GND)
unnamed: U$4.8 (XTAL1), X1.1
unnamed: R2.1, U$6.PLUS
unnamed: RFM12B.ANT, U$1.P$1, U$5.ANA (ANT), X2.3 (SIGNAL)
unnamed: U$4.7 (XTAL2), X1.3
PWR: C2.1, FTDI.3, IC3.3 (VI), SH1.2, SH2.2
RST: C1.1, R3.2, SH2.4, SW1.3 (P1), U$4.4 (RESET)
VCC: C3.1, C4.1, IC3.2 (VO), R3.1, RFM12B.VDD, SH1.3, SH2.3, U$4.5 (VCC), U$4.17 (VCC), U$4.27 (AVCC), U$4.38 (VCC), U$5.VDD (VCC), W25X40CLSNIG-ND.3 (WP), W25X40CLSNIG-ND.7 (HOLD), W25X40CLSNIG-ND.8 (VCC)

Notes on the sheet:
Moteino MEGA
author: Felix Rusu
http://lowpowerlab.com
RFM12B
CC-BY-SA 4.0 License

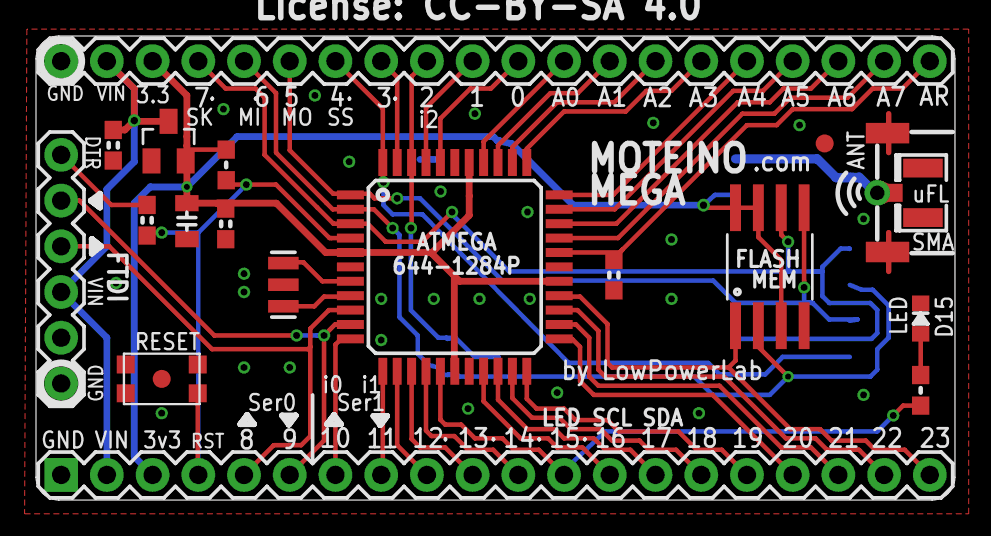
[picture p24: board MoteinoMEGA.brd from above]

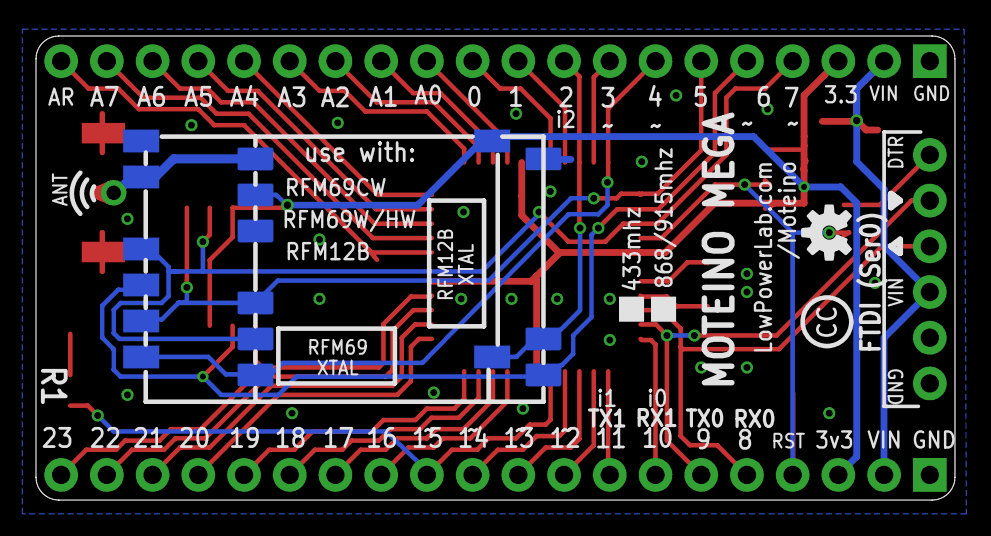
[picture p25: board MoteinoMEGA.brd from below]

Board: 2 copper layers, 51.1 x 25.8 mm, 23 parts (3 on the bottom side), 42 nets.

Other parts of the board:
U$3: OSHW-LOGO-S

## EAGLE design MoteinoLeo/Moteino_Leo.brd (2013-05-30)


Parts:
+: M01PTH; 1X01
C1, C2: 1u; 0603-CAP
C3: 10u; 0805-CAP
C4, C5: 0.1; 0603-CAP
F1: PTC0805; 0805-PTC
IC3: MCP1703CB; SOT23
JP2: M01PTH; 1X01
JP3: USB-MICROB
JP4, JP5: M14; 1X14
R1: 10k; 0603-RES
R2: 1k5; 0603-RES
R3, R4: 22; 0603-RES
RFM12B: RFM12B_MINPADS; RFM12B-MINPADS
U3: ATMEGA32U4; QFN-44-NOPAD
U$1: RFM12B_ANTENNA; RFM12B-ANTENNA
U$2: LED0603; 0603-LED
U$4: AT25F512BJEDEC; SO08
X1: 16Mhz; RESONATOR-SMD

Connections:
A0: JP5.1, U3.36 (PF7(ADC7))
A1: JP5.2, U3.37 (PF6(ADC6))
A2: JP5.3, U3.38 (PF5(ADC5))
A3: JP5.4, U3.39 (PF4(ADC4))
A4: JP5.5, U3.40 (PF1(ADC1))
A5: JP5.6, U3.41 (PF0(ADC0))
AREF: C5.1, JP5.10, U3.42 (AREF)
D0_RXI: JP4.14, U3.20 (PD2(RX))
D1_TXO: JP4.13, U3.21 (PD3(TX))
D2: JP4.12, U3.19 (PD1(SDA))
D3: JP4.11, RFM12B.IRQ, U3.18 (PD0(SCL))
D4: JP4.10, U3.25 (PD4(ADC8))
D5: JP4.9, U3.31 (PC6)
D6: JP4.8, U3.27 (PD7(ADC10))
D7: JP4.7, U3.1 (PE6)
D8: JP4.6, U3.28 (PB4(ADC11)), U$4.1_CS (CS)
D9: JP4.5, U3.29 (PB5(ADC12))
D10: JP4.4, U3.30 (PB6(ADC13))
D11: JP4.3, U3.12 (PB7)
D12: JP4.2, U3.26 (PD6(ADC9))
D13: JP4.1, U3.32 (PC7), U$2.PLUS
D+: JP3.D+, R3.2
D-: JP3.D-, R4.2
GND: C1.2, C2.2, C3.2, C4.2, C5.2, IC3.1 (GND), JP2.1, JP3.GND, JP3.MT1 (GND), JP3.MT2 (GND), JP5.14, R2.1, RFM12B.GND, U3.5 (UGND), U3.15 (GND), U3.23 (GND), U3.33 (PE2/!HWB), U3.35 (GND), U3.43 (GND), U$4.4_GND (GND), X1.2
MISO: JP5.9, RFM12B.SDO (SDO/MISO), U3.11 (PB3(MISO)), U$4.2_SO (SO)
MOSI: JP5.8, RFM12B.SDI (SDI/MOSI), U3.10 (PB2(MOSI)), U$4.5_SI (SI)
unnamed: R2.2, U$2.MINUS
unnamed: RFM12B.ANT, U$1.P$1
unnamed: U3.16 (XTAL2), X1.3
unnamed: U3.17 (XTAL1), X1.1
unnamed: C1.1, U3.6 (UCAP)
unnamed: R3.1, U3.4 (D+)
unnamed: R4.1, U3.3 (D-)
RST: JP5.11, R1.1, U3.13 (!RESET)
SCK: JP5.7, RFM12B.SCK, U3.9 (PB1(SCK)), U$4.6_SCK (SCK)
SS: RFM12B.SEL, U3.8 (PB0(SS))
TXO: U3.22 (PD5)
USBPOWER: F1.2, JP3.VBUS
VBUS: C2.1, F1.1, IC3.3 (VI), JP5.13, U3.2 (UVCC), U3.7 (VBUS)
VCC: +.1, C3.1, C4.1, IC3.2 (VO), JP5.12, R1.2, RFM12B.VDD, U3.14 (VCC), U3.24 (AVCC), U3.34 (VCC), U3.44 (AVCC), U$4.3_WP (WP), U$4.7_HOLD (HOLD), U$4.8_VCC (VCC)

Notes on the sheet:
Moteino Leo
author: Felix Rusu
http://lowpowerlab.com
(CC) Attrib ShareAlike



Board: 2 copper layers, 35.8 x 23.1 mm, 23 parts (2 on the bottom side), 39 nets.

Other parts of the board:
U$3: OSHW-LOGO-S

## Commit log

2012-12-28 Add Moteino Eagle files
    [Moteino.brd, Moteino.sch, Moteino_BOM.xlsx]
2013-03-12 R2 Update
    [Moteino.brd, Moteino.sch]
2013-05-30 Update to R1 production schematic
    [Moteino_Leo.sch]
2013-05-30 Update to R1 production board
    [Moteino_Leo.brd]
2013-06-25 Add R2 and R3 Eagle files
    [Moteino.brd, Moteino.sch, Moteino_BOM.xlsx]
2013-10-24 Add Moteino R4 & R4-USB
    [Moteino.brd, Moteino.sch]
2013-12-23 Update Eagle files, add schematic PDFs
    [Moteino.brd, Moteino.sch]
2014-01-21 Remove MFGCode
    [Moteino.brd]
2014-02-03 Add stencil PNGs
    You can print these on vinyl and then toner transfer to soda can
    interior, then etch it in muriatic acid + hydrogen peroxide (1+3 parts
    solution). Instructions at:
    http://lowpowerlab.com/blog/2013/02/11/diy-smd-metal-stencils-the-definitive-tutorial/
2014-07-29 Update BOM
    [Moteino_BOM.xlsx]
2014-08-09 Add MoteinoMEGA
    [MoteinoMEGA.brd, MoteinoMEGA.sch, Moteino_BOM.xlsx]
2014-08-10 Update Eagle files
    [Moteino.brd, Moteino.sch]
2014-08-10 Add MEGA Arduino Core
2015-03-13 Update core for Arduino 1.6.1
2015-04-26 Add dimension files
    [Moteino.dxf, MoteinoMEGA.dxf, MoteinoUSB.dxf]
2015-10-13 Add Motein oR5-USB
    [MoteinoR5USB.brd, MoteinoR5USB.sch, MoteinoR5USB_dimension.dxf]
2016-02-17 Add LoRa board & schematic
2018-05-06 Add MoteinoR6 design files
    [Moteino.brd, Moteino.dxf, Moteino.sch]
2018-11-19 add M0 header layout
    [MoteinoM0_HeaderLayout.brd, MoteinoM0_HeaderLayout.sch]
2020-09-03 Add RFM69HCW breakout
    [RFM69HCW_Breakout.brd, RFM69HCW_Breakout.sch]

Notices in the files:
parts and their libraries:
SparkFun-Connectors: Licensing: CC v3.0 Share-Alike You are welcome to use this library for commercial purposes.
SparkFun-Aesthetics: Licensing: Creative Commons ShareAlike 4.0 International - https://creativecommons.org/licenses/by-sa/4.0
